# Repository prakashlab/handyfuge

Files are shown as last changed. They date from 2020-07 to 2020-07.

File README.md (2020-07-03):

# handyfuge
Mechanical design files for a portable hand-powered centrifuge.

Photograph of the v0.1.0 prototype, showing the freewheel mechanism and the rotor to hold microcentrifuge tubes:

<p float="left">
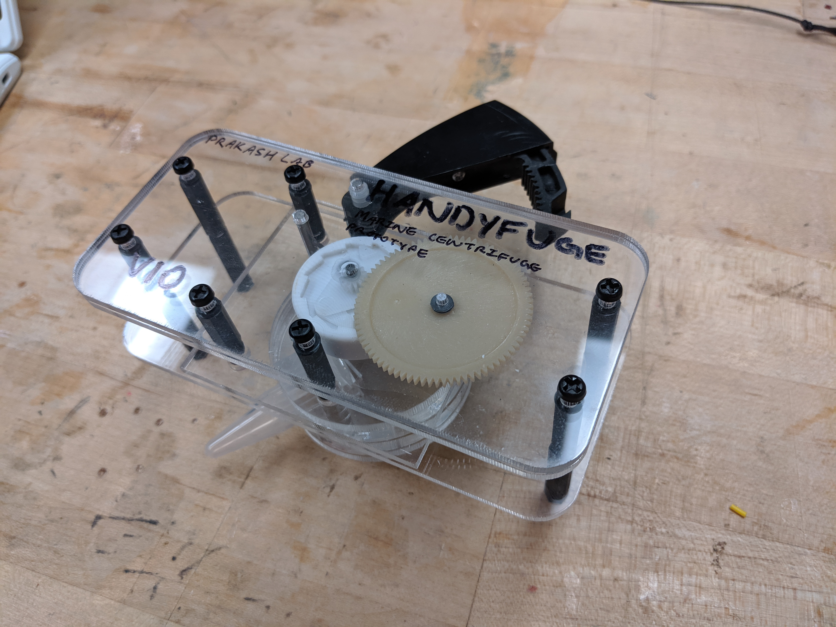
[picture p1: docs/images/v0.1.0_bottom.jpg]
v0.1.0 prototype, bottom view
  
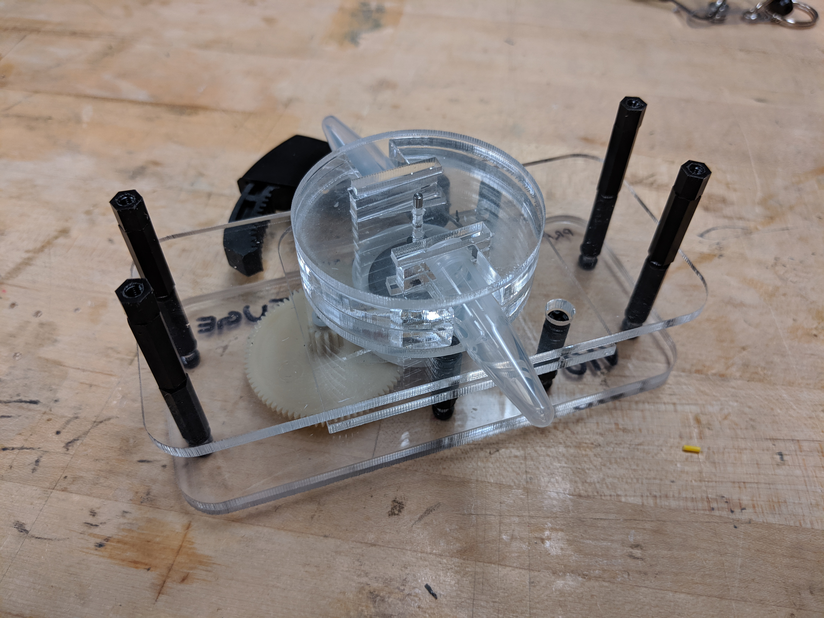
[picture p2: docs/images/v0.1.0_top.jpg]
v0.1.0 prototype, top view
  
</p>

Photographs of the v0.2.1 prototype, showing the rotor guard to provide more mechanical enclosure of the rotor and taped-down electronics for measuring the rotational speed of the rotor:

<p>
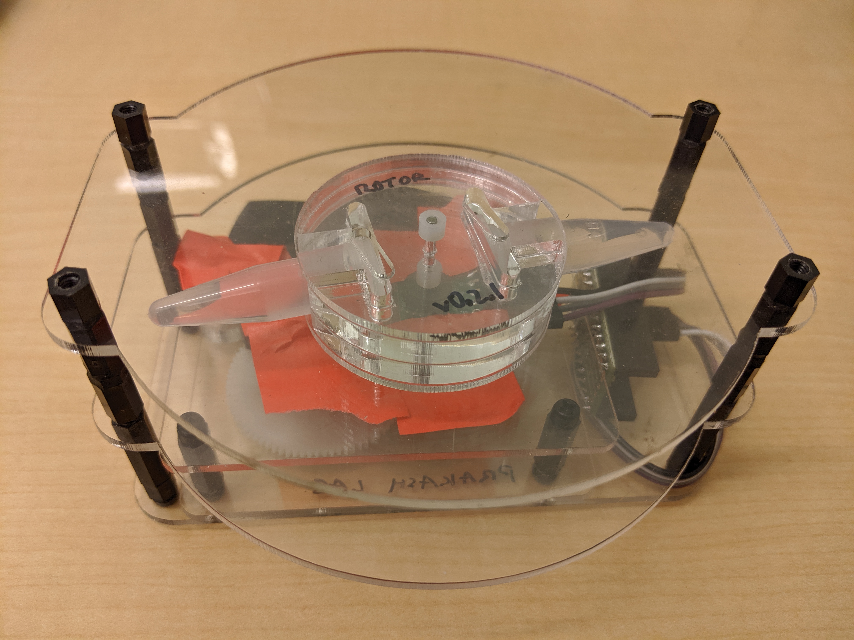
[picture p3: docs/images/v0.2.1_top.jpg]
v0.2.1 prototype, top view
  
</p>

## Designs

The CAD sources for these designs can be viewed and copied [at Onshape](https://cad.onshape.com/documents/2cf671f300bec1e37c7aebdd/w/50c80549fc61639971846d73/e/14e672d36cf51ed47f4d48e6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). Laser-cutting fabrication files, generated from the CAD sources, can be found in the `design` folder of this repository, organized by prototype version. Version numbering loosely follows the [semantic versioning specification](https://semver.org/), such that tiny design iterations increase the patch version number while significant new design features increase the minor version number, and backwards-incompatible public releases increase the major version number. More information about each prototype version can be found in the `README.md` file in the subfolder for that prototype version.

Photographs of prototype designs can be found [here](https://drive.google.com/drive/folders/1ZNTd_ySJtXn2qwRWTb83T112aYDAMxPa?usp=sharing).

## Manuscripts

\* indicates equal contributions, while † denotes corresponding author.

**Handyfuge-LAMP: low-cost and electricity-free centrifugation for isothermal SARS-CoV-2 detection in saliva**

- Ethan Li\*, Adam Larson\*, Anesta Kothari, Manu Prakash†
- Correspondence: manup at stanford dot edu
- [medRxiv preprint](https://www.medrxiv.org/content/10.1101/2020.06.30.20143255v1), July 2020

## License

The Handyfuge designs, including all associated design files, are made available under CERN-OHL-W (SPDX identifier: [CERN-OHL-W-2.0](https://spdx.org/licenses/CERN-OHL-W-2.0.html)), the weakly-reciprocal variant of the [CERN Open Hardware License](https://ohwr.org/project/cernohl/wikis/Documents/CERN-OHL-version-2). You can read the text of the license in the `LICENSE` file.

## Contact

To report issues with the designs or get help with using these designs, please [file an issue](https://github.com/ethanjli/handyfuge/issues/new). Please be aware that it may take a while for us to fully address issues (e.g. putting together a bill of materials for mechanical parts used in the designs), because of ongoing research disruptions from the COVID-19 situation.

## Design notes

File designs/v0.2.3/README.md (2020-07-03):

# v0.2.3 Prototype

This prototype version is a modification by Anesta Kothari of the v0.2.2 design for release in the [Handyfuge-LAMP preprint on medRxiv](https://www.medrxiv.org/content/10.1101/2020.06.30.20143255v1) to be easier to assemble:

- The rotor core plates were split up into 2 mm plates, to remove the need for cutting 1/4"-thick acrylic for the rotor core.
- The laser-cut part patterns were panelized into a single sheet.
- The rotor guard was removed to save space for panelization.

## Assembly

Assembly instructions for this prototype have not been created, but a stackup showing the ordering and alignment of plates is shown in Fig. 1 of the Handyfuge-LAMP preprint on medRxiv. This design uses M3 standoffs for structural support, as well as M2 and M3 dowel pins of various lengths, and some washers and spacers from McMaster-Carr.

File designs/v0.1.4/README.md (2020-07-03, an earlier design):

# v0.1.4 Prototype

This prototype version is the first created by Ethan Li to be assembled by taking parts from a single hand-squeeze flashlight for use with a rotor which can spin microcentrifuge tubes.

## Assembly

Assembly instructions for this prototype have not been created, but photos of the assembled prototype [are available](https://drive.google.com/drive/folders/1QE24hF5hobyn_T7r6Pj2J-EpUPVJ-oRx?usp=sharing). This design uses M3 standoffs for structural support, as well as M2 and M3 dowel pins of various lengths, and some washers and spacers from McMaster-Carr.

## Applications

This prototype version was the device used by Adam Larson for the LAMP assay presented in the July 1, 2020 version of the [Handyfuge-LAMP preprint on medRxiv](https://www.medrxiv.org/content/10.1101/2020.06.30.20143255v1).

## Forking

The Onshape CAD for this prototype version can be found in the ["Bear Squeeze Reconstruction" part studio of the v0.1.4 version](https://cad.onshape.com/documents/2cf671f300bec1e37c7aebdd/v/0b79bdd1a180958896d4d577/e/14e672d36cf51ed47f4d48e6) of the Onshape workspace. Part configurations are available for 0.6 mL tubes, 1.5 mL tubes, and 2.0 mL tubes. The laser cut files for this version were created by selecting the appropriate face of each part in the part studio and exporting as DXF files; in these files, the length unit is mm.

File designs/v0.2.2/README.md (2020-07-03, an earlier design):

# v0.2.2 Prototype

This prototype version is a major evolution by Ethan Li on the v0.1.4 design, to add several design features to improve the safety, reliability, and speed of the handyfuge:

- A rotor guard adds physical shielding to reduce the risk of accidentally hitting the centrifuge tubes while the device is being operated.
- Support plates at the squeeze handle prevent the squeeze handle from jamming on the edges of nearby acrylic plates.
- A dowel pin constrains the relaxation of the squeeze handle to prevent wasted travel.
- Minor dimensional adjustments reduce friction and improve device performance and usability.
- The locations of the holes for the outer frame standoffs are standardized to be spaced in multiples of 5 mm.

## Assembly

Assembly instructions for this prototype have not been created, but photos of the assembled prototype [are available](https://drive.google.com/drive/folders/1sdI5_rqlt_9IgPVxCfTqWUPCU-ixx4wc?usp=sharing). This design uses M3 standoffs for structural support, as well as M2 and M3 dowel pins of various lengths, and some washers and spacers from McMaster-Carr.

## Applications

This prototype version was the device used by Ethan Li for the device characterization presented in the July 1, 2020 version of the [Handyfuge-LAMP preprint on medRxiv](https://www.medrxiv.org/content/10.1101/2020.06.30.20143255v1).

## Forking

The Onshape CAD for this prototype version can be found in the ["Compact (v0.2.2)" part studio of the v0.2.2 version](https://cad.onshape.com/documents/2cf671f300bec1e37c7aebdd/v/64f6927857a6e069a135ad2d/e/14e672d36cf51ed47f4d48e6) of the Onshape workspace. Part configurations are available for 0.6 mL tubes, 1.5 mL tubes, and 2.0 mL tubes; and with or without a rotor guard to reduce the risk of foreign objects hitting centrifuge tubes; and with different rotor diameters. The laser cut files for this version were created by selecting the appropriate face of each part in the part studio and exporting as DXF files; in these files, the length unit is mm.

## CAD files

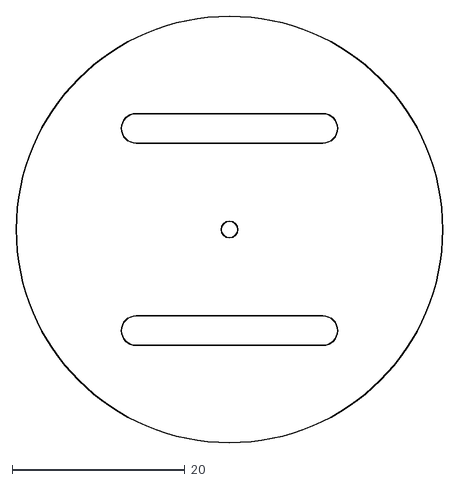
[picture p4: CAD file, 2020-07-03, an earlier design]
designs/v0.1.4/1.5 mL tubes/0.125 in/Rotor Cap 1.dxf
49.4 x 49.4

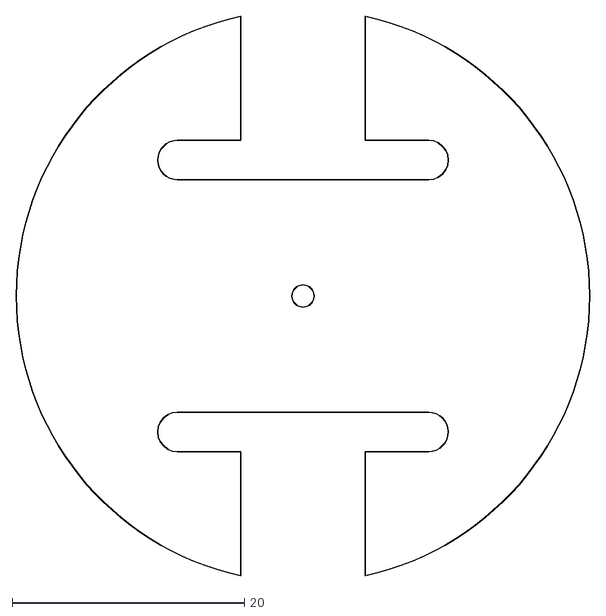
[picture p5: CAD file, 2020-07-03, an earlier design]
designs/v0.1.4/1.5 mL tubes/0.25 in/Rotor Core 2.dxf
49.4 x 48.2

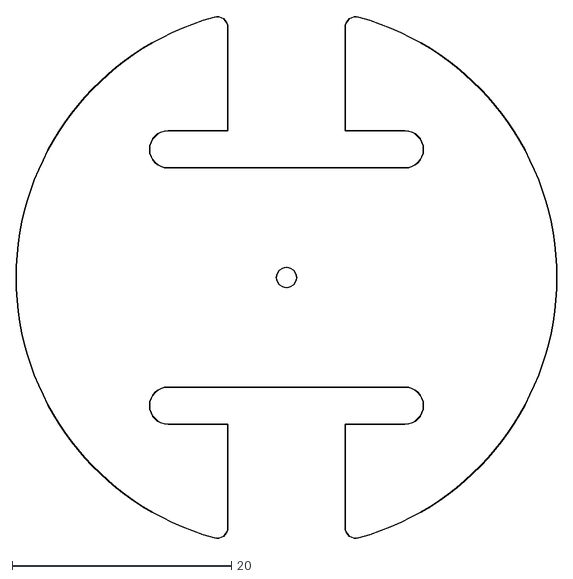
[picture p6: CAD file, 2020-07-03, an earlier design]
designs/v0.2.2/1.5 mL tubes, rotor guard, small rotor/0.25 in/Rotor Core 2.dxf
49.4 x 47.7

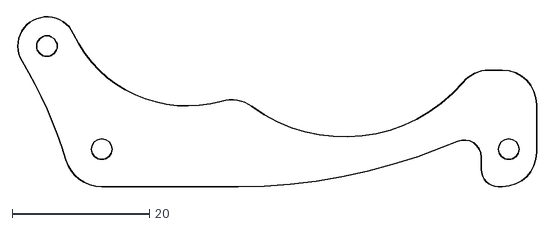
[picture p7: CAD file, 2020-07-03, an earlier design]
designs/v0.2.2/1.5 mL tubes, rotor guard, small rotor/2 mm/Squeeze Handle Support Base 2.dxf
75.7 x 24.8

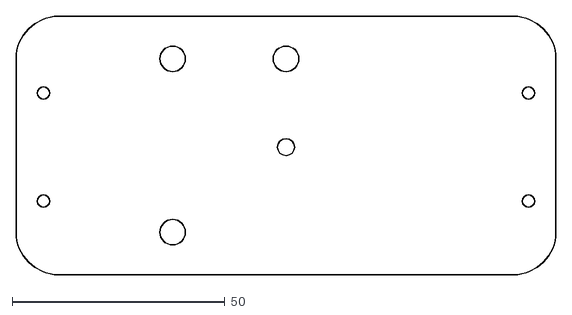
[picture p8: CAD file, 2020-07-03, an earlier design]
designs/v0.1.4/1.5 mL tubes/0.125 in/Rotor Base.dxf
126.9 x 60.8

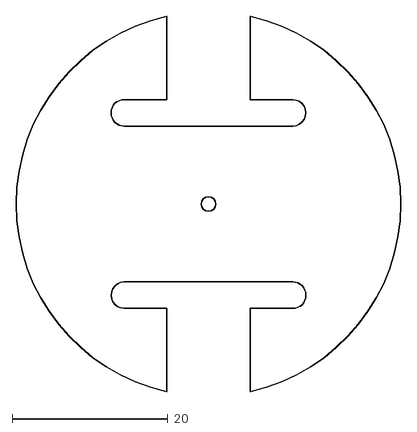
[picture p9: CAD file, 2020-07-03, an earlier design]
designs/v0.1.4/1.5 mL tubes/0.25 in/Rotor Core 1.dxf
49.4 x 48.2

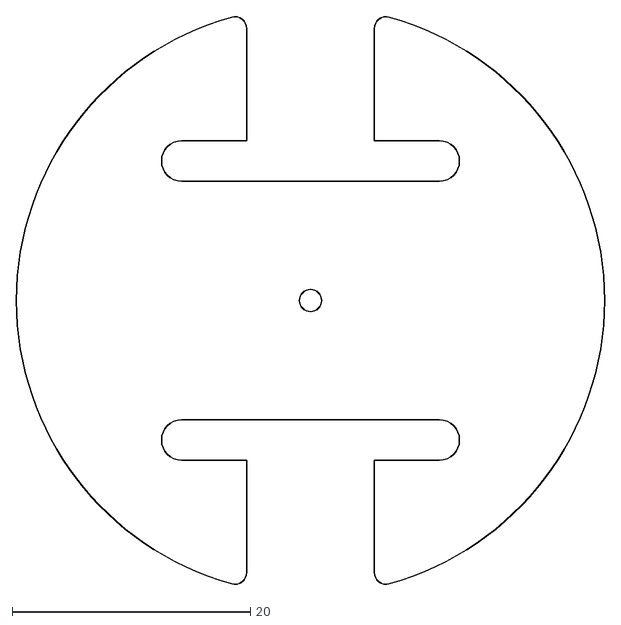
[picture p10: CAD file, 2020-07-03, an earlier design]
designs/v0.2.2/1.5 mL tubes, rotor guard, small rotor/0.25 in/Rotor Core 1.dxf
49.4 x 47.7

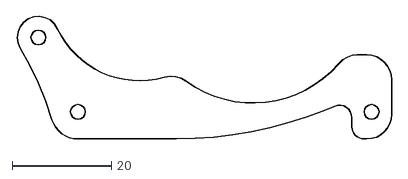
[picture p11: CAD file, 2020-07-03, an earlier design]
designs/v0.2.2/1.5 mL tubes, rotor guard, small rotor/2 mm/Squeeze Handle Support Base 1.dxf
75.7 x 24.8

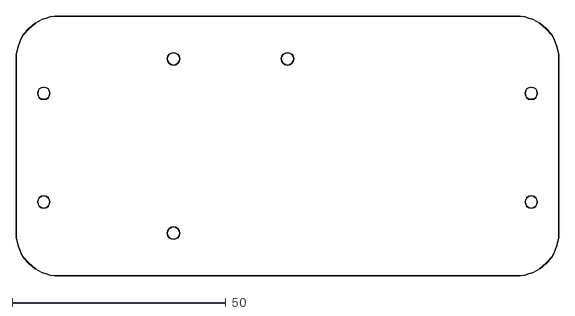
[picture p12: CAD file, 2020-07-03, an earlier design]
designs/v0.1.4/1.5 mL tubes/0.125 in/Base.dxf
126.9 x 60.8

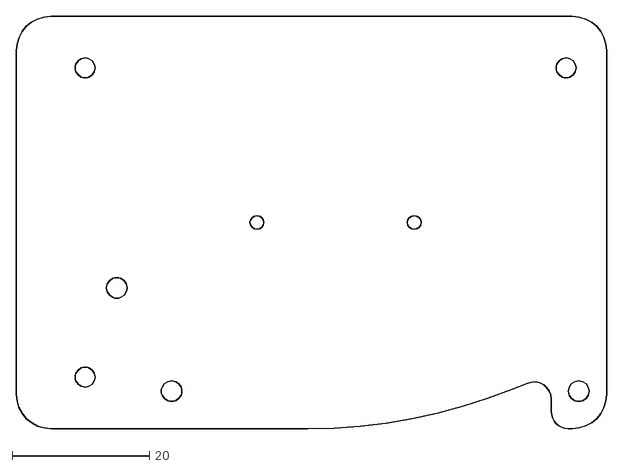
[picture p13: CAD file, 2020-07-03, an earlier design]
designs/v0.2.2/1.5 mL tubes, rotor guard, small rotor/2 mm/Lower Axle Footprint.dxf
85.9 x 60.0

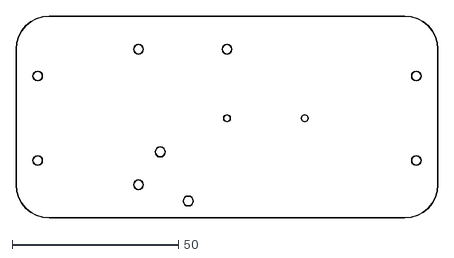
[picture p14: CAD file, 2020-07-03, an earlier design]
designs/v0.1.4/1.5 mL tubes/0.125 in/Lower Axle Footprint.dxf
126.9 x 60.8

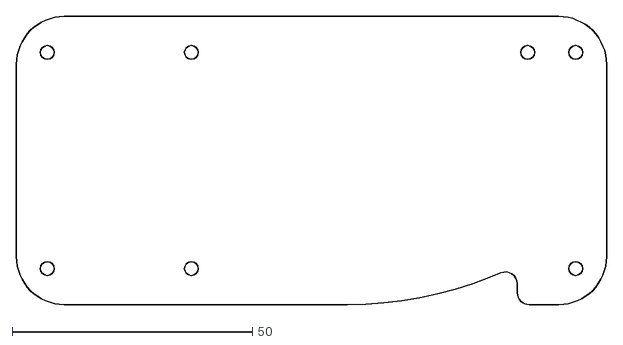
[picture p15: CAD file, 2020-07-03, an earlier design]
designs/v0.2.2/1.5 mL tubes, rotor guard, small rotor/2 mm/Outer Base.dxf
122.9 x 60.0

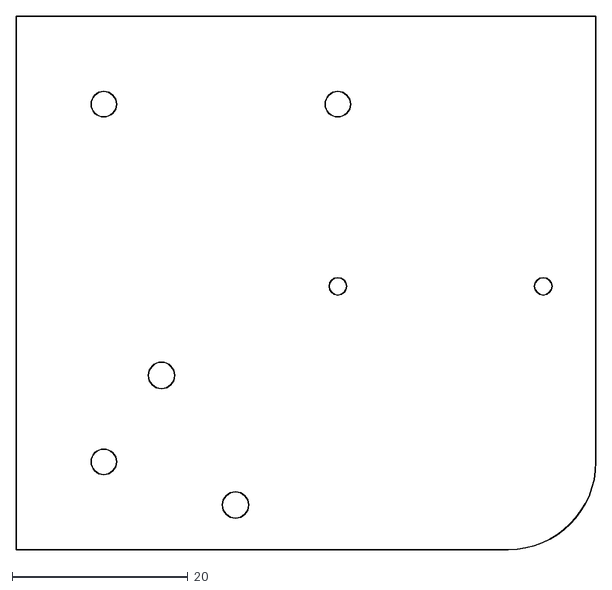
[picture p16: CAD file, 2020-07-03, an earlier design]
designs/v0.1.4/1.5 mL tubes/0.125 in/Upper Axle Footprint.dxf
66.0 x 60.8

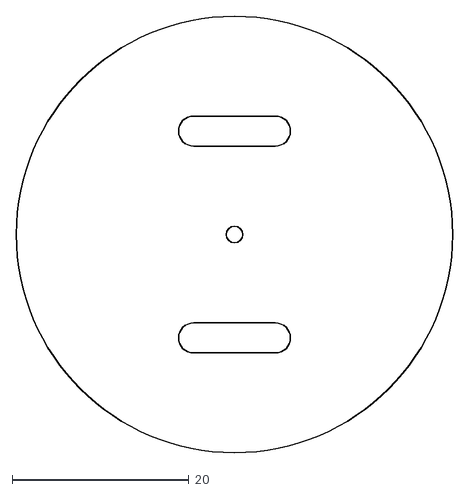
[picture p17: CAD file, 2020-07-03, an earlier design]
designs/v0.2.2/1.5 mL tubes, rotor guard, small rotor/2 mm/Rotor Cap 2.dxf
49.4 x 49.4

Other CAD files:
designs/v0.1.4/1.5 mL tubes/0.125 in/Rotor Cap 2.dxf
designs/v0.2.2/1.5 mL tubes, rotor guard, small rotor/2 mm/Rotor Cap 1.dxf
designs/v0.2.2/1.5 mL tubes, rotor guard, small rotor/2 mm/Rotor Holder.dxf
designs/v0.2.2/1.5 mL tubes, rotor guard, small rotor/2 mm/Upper Axle Footprint.dxf
designs/v0.2.2/1.5 mL tubes, rotor guard, small rotor/2 mm/Rotor Base.dxf

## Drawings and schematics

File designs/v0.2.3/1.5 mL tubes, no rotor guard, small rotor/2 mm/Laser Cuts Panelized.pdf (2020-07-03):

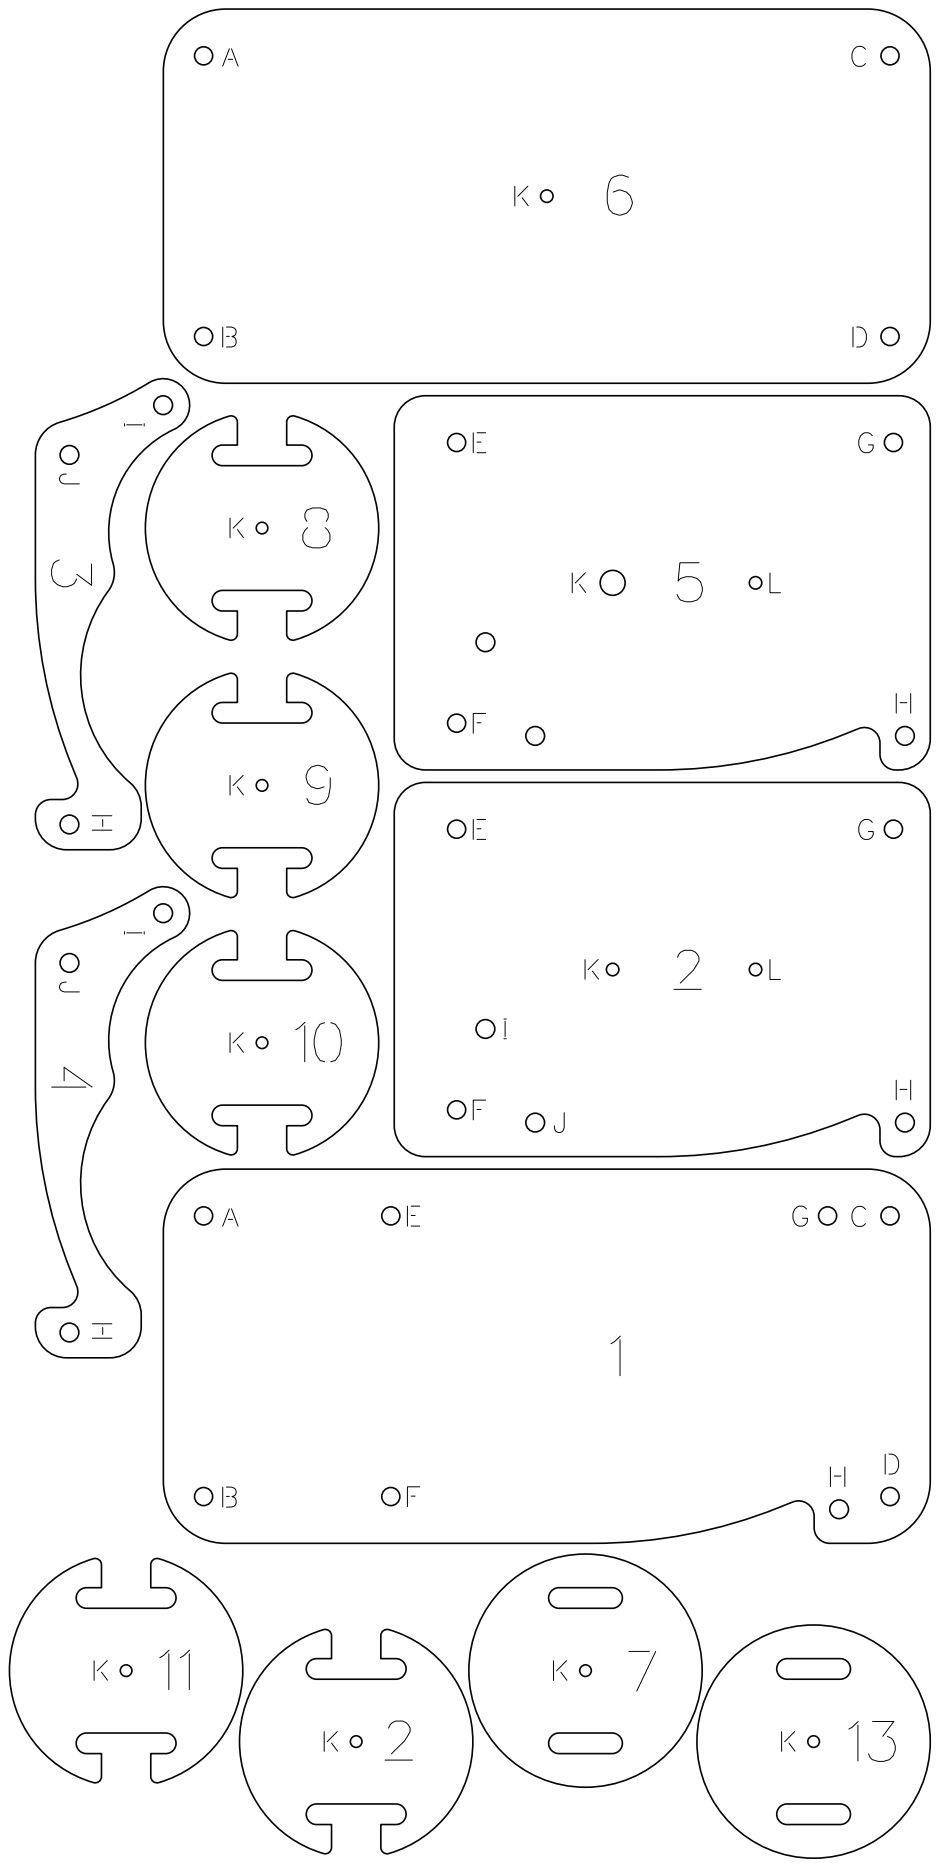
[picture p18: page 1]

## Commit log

2020-07-03 Initial release of prototype design files.
    [Base.dxf, Lower Axle Footprint.dxf, Outer Base.dxf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]
2020-07-03 Added READMEs to prototype versions.
    Fixed organization of files.
    [Base.dxf, Lower Axle Footprint.dxf, Rotor Base.dxf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]
